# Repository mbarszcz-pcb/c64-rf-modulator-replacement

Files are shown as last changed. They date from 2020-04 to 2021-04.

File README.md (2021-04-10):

# c64-rf-modulator-replacement
C64 Composite/S-Video RF Modulator Replacement

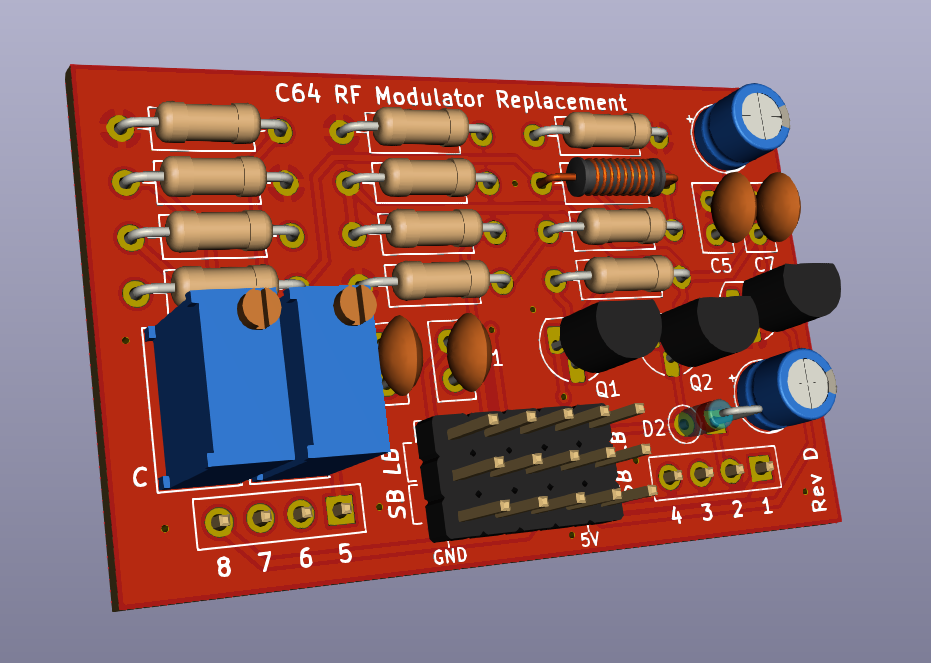
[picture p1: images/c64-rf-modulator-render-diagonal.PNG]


## Quick Links
* [Schematic](pdf/c64-rf-modulator-replacement-schematic.pdf)

* [Gerber Files](gerbers)

* [PCB Renderings](images/pcb)

* [Photos](images/photos)

# Introduction 
This is my version of a C64 RF Modulator replacement based on the schematics of similar designs like [Zero-X/OMS's Modified Commodore RF Modulator Design](images/zerox-oms-modulator_simple-schematic.png) and [JMP$FCE2's S-Video only design](images/jmp$fce2-schematic.png).  This board can be used to replace a damaged or defective RF modulator in your C64, to improve the sharpness of your video output, or as a modern solution to replace the composite/luma/chroma output functionality of the original modulator on new motherboards such as the SixtyClone or Bwack’s KU-14194.

This design has a few goals that set it apart from the others:

1.	It is a universal solution that fits and is electrically compatible with both the C64 and C64C without having to change components on the board or run jumper wires for power.

2.	It is easy and inexpensive to build with only a single, small PCB and all through-hole components.

3.	It provides [high quality S-Video (Y/C) output](images/photos/video-output-6569-r5.png) while maintaining composite video output for compatibility.

4.  It provides adjustable luma/chroma output levels to fine-tune the S-video signal. This allows for the best possible compatibility with a wide variety of different board revisions, VIC chips, aging components and monitors. Adjustable levels  mean this board can also be used with s-video cables with or without an inline resistor to eliminate “checkerboarding” caused by too high of a chroma level.

# Compatibility
This RF modulator replacement is compatible with motherboard revisions 250407, 250425, 250466, and 250469, and both NTSC and PAL VIC-II chips. I have not tested it, but I believe it should also be compatible with Bwack's KU-14194 board as well since it uses the standard longboard RF modulator. It is not compatible, however, with the early revision 326298-01 boards with the 5 Pin AV Output. This revision uses a different modulator pin layout, and the video signals are not combined in the modulator. They are instead processed with discrete components inside the VIC-II can.

# Gathering the components
Kicad files are available for you to view or modify as you see fit. Gerber files are available that can be uploaded directly to your favorite PCB fab to make your own boards, and a complete Bill of Materials (BOM) can be found [here](c64-rf-modulator-replacement-bom.xlsx) with example parts from Digikey. At the time of writing this, the components cost about $12 US, not including the PCB or shipping.

I strongly recommend building the entire board, if you choose to do so, there are a few components that can be omitted in different situations to decrease the cost at the expense of features and flexibility.

## Trimmers
The trim pots used to adjust the luma and chroma are the most expensive components in this project. I highly recommend using them, but if you choose, you may jumper the solder bridges on the back of the board to bypass the trimmer pads and install 150 Ohm resistors for R4 and R7. This won't give you the precision adjustment of the trimmers, but it will be close enough for most configurations. You can experiment with different fixed value resistors between 100-1K Ohm if you want to change fixed output levels.

## No Composite Video
I have not seen any improvement in S-video quality by omitting the composite video components, but if you really don’t want composite output, L2, R8, R11, and C6 can be omitted from the build.

## No Voltage Regulator
If you are only ever going to use the RF modulator replacement on a C64C 250469 short board, you don’t need the voltage regulator or the input/output capacitors since 5V is provided directly to the modulator on pin 1. This means you can omit C3, C5, C7, C8, and U1 from the build.

# Building the board
Once you have your PCBs and all your components, soldering them together should be pretty straightforward. You can use the schematic or the BOM to place the right value parts in the right place. From a soldering standpoint, it is easiest to assemble the components starting with the lowest profile first and then work your way up. This would be mean soldering the resistors and inductor first, then the ceramic caps, the diode, electrolytic capacitors, transistors and voltage regulator, and finally, the jumper block. The jumpers can then be installed on the headers in the appropriate configuration. Finish off by removing the flux residue with some cotton swabs or a brush and isopropyl alcohol.

# Installing the board
First, you need to remove the old RF modulator. This can be a bit tricky as the large metal can will suck the heat right out of the iron. I can’t help you much here, but I can only suggest you use a soldering iron with plenty of heat, use a wide tip, to take your time, and don't rip off any traces. The new board can then be installed one of two ways.

The first is soldering it directly to the motherboard. For this, you can solder two .1” pin headers into the motherboard (making sure they are straight) and then setting the RF modulator replacement down on top of them. I recommend sticking small rubber feet near the rear of the board to help support it. You can slide two feet under the front of the rf modulator replacement to keep the pcb level and evenly spaced all the way around while you solder the headers from the top side. Trim the excess length of the header pins off and slide out the rubber feet. For a nicer finish, reflow the solder joints after you have trimmed them.

Alternatively, you can make the replacement a bit more modular by soldering two 4-pin female headers on the motherboard and two 4-pin male headers on the RF modulator replacement. This will allow you to plug and unplug the modulator easily. It is not required, but as the board will be approximately ½” above the motherboard and “hanging” on the headers, you may want to use some rubber feet, foam, or double-sided tape as a spacer to support the back of the board.

# Adjustments

## Configuring the mainboard
If you are using the longboard (Rev 250407, 250425, 240441, 250466) it is important to make sure the G.PAL/I.PAL jumper by the modulator is SHORTED, or the ground pin the modulator replacement attaches to will be floating and will not work correctly.  You can validate this by checking continity between the left most RF modulator through-hole on the C64 motherboard and a suitable ground point on the C64 motherboard (Cartridge shield, plated edge of the moatherboard, 5V Regulator heatsink, etc).  If the modulator is installed, you can also check continutiy between the bottom left pin on the jumper block and a suitable ground point.

## Jumper Settings
The adjustment of the jumpers routes the signals to the proper pinout for the motherboard you are using, switches the correct pull-up resistor for the VIC-II luma, and enables or disables the use of an onboard 5V regulator.With all jumpers in the up position, the board is configured for use on the 12V C64 “longboards” (250407, 250425, and 250466). In this configuration, the 5V regulator is used to regulate the 9V Unregulated power on pin 1 down to 5V

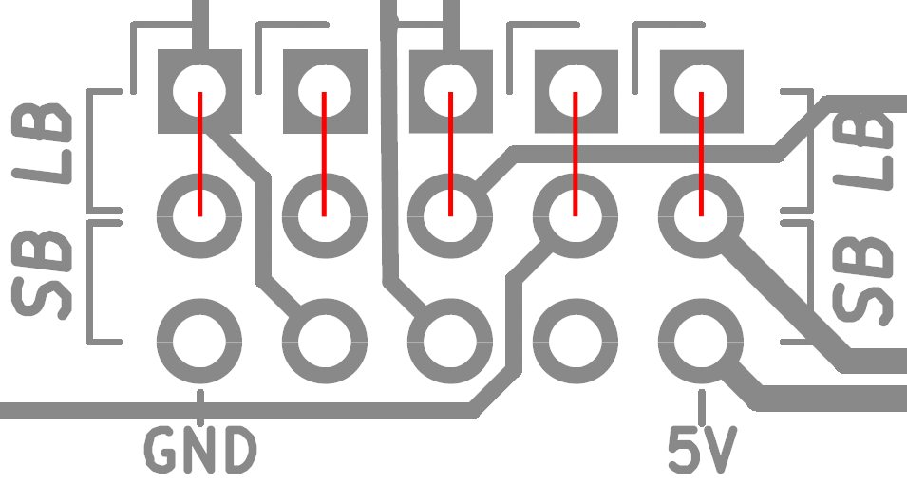
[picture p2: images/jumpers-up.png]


With all jumpers in the down position, the board is configured for use on the 250469 “short board” commonly found in the C64C. In this configuration, the 5V input on pin 1 is fed directly in the circuit without the need for the 5V regulator. Be sure you are using a short board if all the jumpers are down, or you could accidentally fry your VIC-II by accidentally feeding it 9V unreg from a long board.

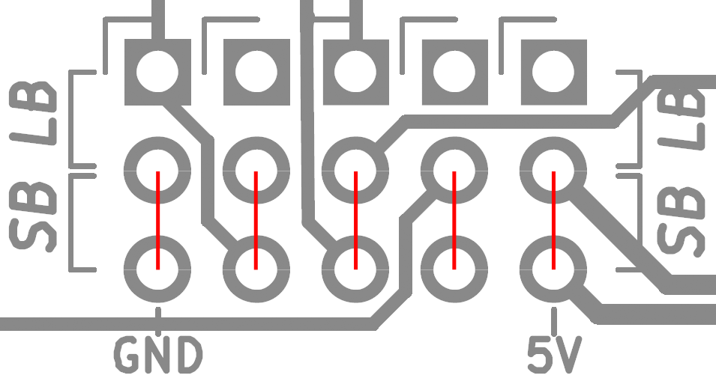
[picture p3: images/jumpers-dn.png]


For most configurations, the jumpers should be either all up or all down; however if you understand what you are doing and want to run a 5V 856x VIC-II from a short board in a 12V long board, there is one jumper that you may want to run in a non-standard configuration. First, you MUST isolate pin 13 on the VIC-II socket from the VIC-II (the short board outputs 12V there while an 856x is expecting 5V). Pin 13 on the VIC-II can then be connected to pin 40 (which is 5V Vcc). I recommend not modifying the VIC-II chips but instead using a piggyback socket or PCB. With a standard machined pin socket, simply trim off leg 13 and solder a jumper wire from leg 13 to 40. The 856x VIC-II can then just plug into the socket without any damaging modifications. Once the VIC-II is installed, the jumpers on the RF modulator should be in the following configuration to use the correct short board 1K pullup resistor:

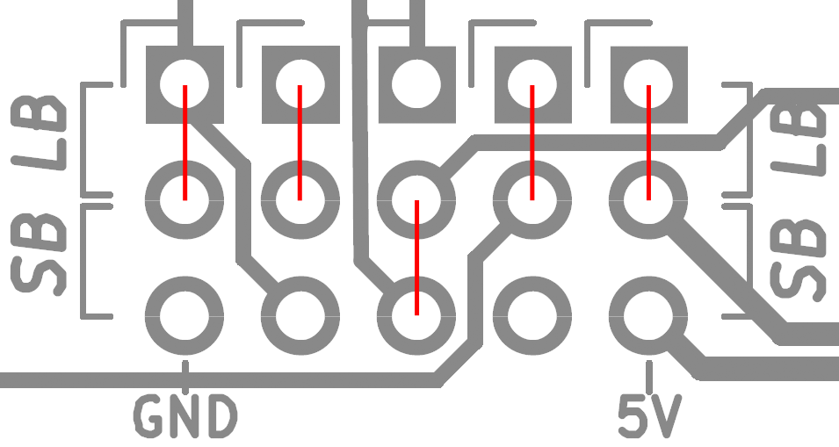
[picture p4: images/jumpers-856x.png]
 	

## Adjusting the Output Level
If you choose to include adjustable potentiometers in your build, a counter-clockwise adjustment on the luma (Y) and chroma (C) potentiometers will reduce the output level. A clockwise adjustment will increase the output level. My recommendation is to start with both adjustments fully counter-clockwise and increase as necessary. The levels can be set with a scope or simply “by eye” depending on the tools you have available.

An ideal chroma signal should be ~300mV peak-to-peak. The adjustment on the board should allow you to adjust it from approximately ~250mV - 1.7V. This range allows you to dial back the output for use with a standard S-video cable or to turn it up to compensate for the cables with the inline 330-1K resistor. Some monitors don't care if the signal is too hot, others will give you an ugly checkered pattern (especially LCDs). If you don't have an oscilloscope to measure the peak-to-peak voltage, start with the chroma pot fully counter-clockwise and increase it until the colors are sufficiently saturated. If you go too far, the image will begin to look “grainy” or have a checkerboard pattern.

Officially, an ideal luma signal should be 1V PP (including the sync pulse). Depending on the output of the VIC-II chip you are using, the adjustment on the board should allow you to adjust it from approximately ~575mV-1.5V PP. The original breadbins output a signal around 1.2V PP, while the later C64Cs were closer to an “in-spec” 1V PP. On some monitors though 1V PP can look too look dark (requiring you to turn up the contrast on your monitor). If using a scope, I would adjust it to approximately 1.1V PP.  If adjusting by eye, start  low and increase the level until the light blue text is reasonably legible against the dark blue background. If the border and text start to look “white” you have gone too far. Another good test on a CRT is white text on a black background. If the white text is blooming, you should back the signal off. The effect will be very similar to having the contrast set too high.

Composite video output remains at a fixed output level regardless of the Y and C adjustment pots.

# A note on use with LCD Monitors and Checkerboarding
If you are still getting checkerboarding even after adjusting the potentiometers, try soldering a 330pF Resistor (you can experiement with different values to see what works best with your setup) across R3 (the resistor on the top right corner of the board).  This combines with R3 to create an RC filter that seems to help eliminate this.  There seems to be a degree of variablility regarding different A->D conversion cirtuitry used in different brands of LCD monitors and in devices like the RetroTink2X or OSSC that makes some displays more susceptable to checkerboarding.  From what I've been able to see, CRT monitors are not susceptable to this behavior.

# Changelog
Rev A – 2020-03-15 - Prototype

Rev B – 2020-03-25 - Initial production revision, fixed schematic bugs, tweaked values and removed unnecessary components to improve picture quality

Rev C – 2020-04-05 - Adjusted positioning of several traces, vias, and regulator U1 to improve physical spacing. Changed RV1 and RV2 for "W" footprint trimmers with inline legs due to parts availability. Swapped R4 and R5 physical locations to better accomodate the new pin configuration

Rev D – 2020-04-07 - Adjusted power and ground trace thickness, added additional vias, added custom trimmer footprint to ID proper placement, optimized ground pours, increased chroma/luma/power trace isolation

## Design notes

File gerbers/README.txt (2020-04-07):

Always use the latest revision PCB.

"-gerbers-jlc.zip" is the PCB with JLCJLCJLC on the B Silkscreen layer for unique ID during board production and proper options for JLCPCB.  Be sure to select "specify a location" when ordering from JLCPCB.

"-gerbers-pcbway.zip" are the gerbers exported with the proper options for pcbway

Recommended board values:
	PCB Thickness: 1.6mm
	Copper Weight 1oz
	Castellated Holes - No
	Tented Vias - Yes
	Surface Finish - Personal preference

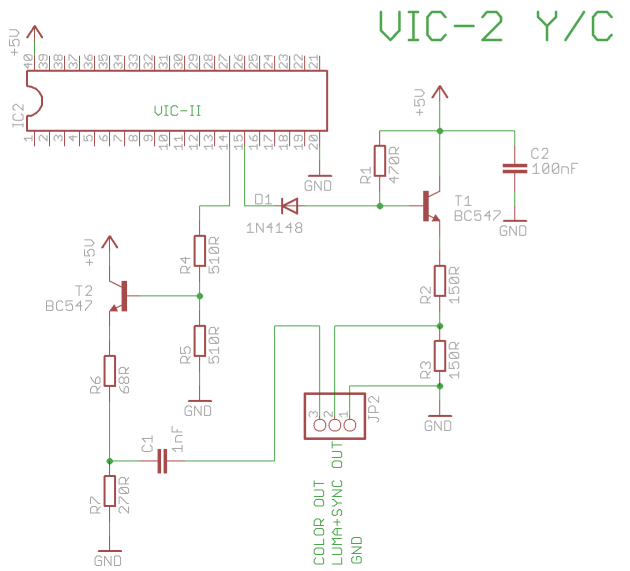
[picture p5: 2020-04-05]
images/jmp$fce2-schematic.png

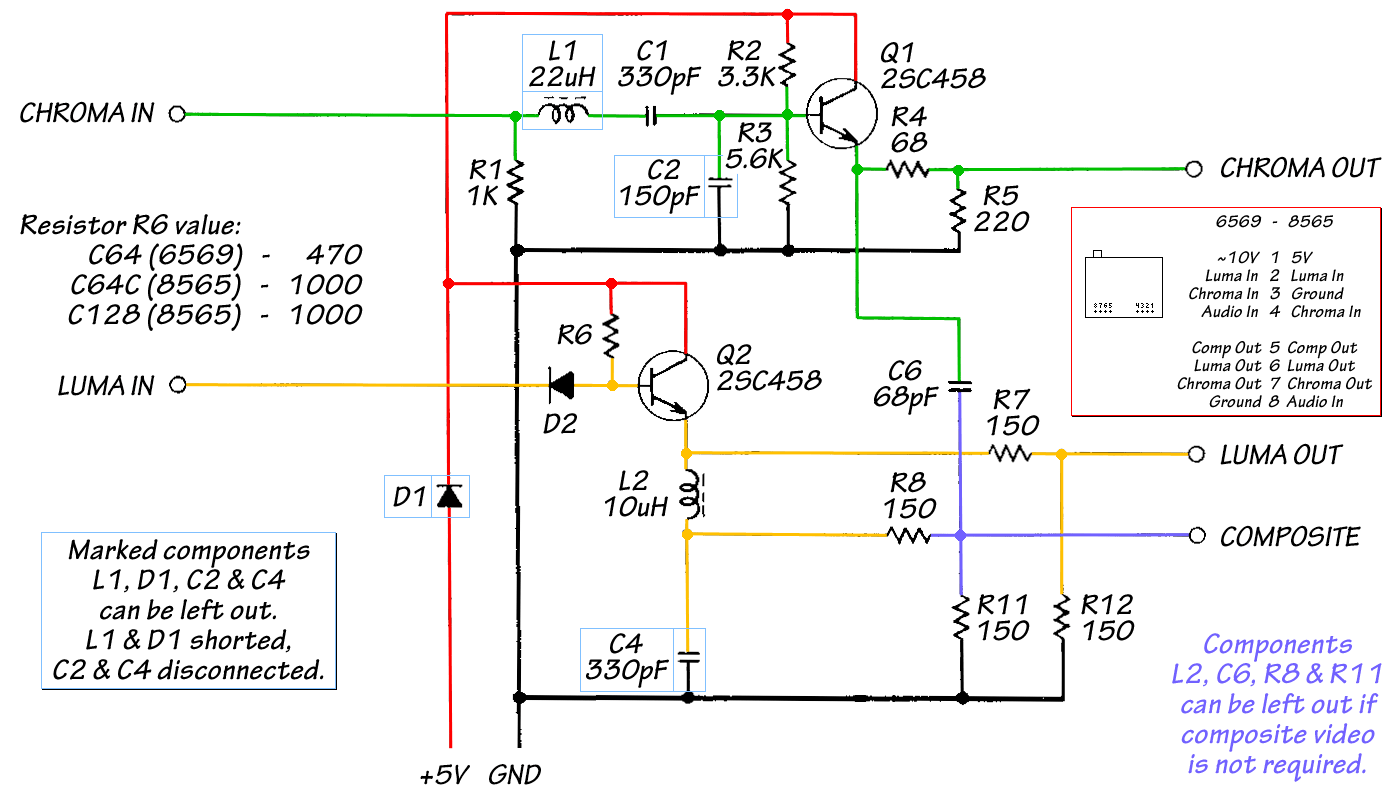
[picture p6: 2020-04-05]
images/zerox-oms-modulator_simple-schematic.png

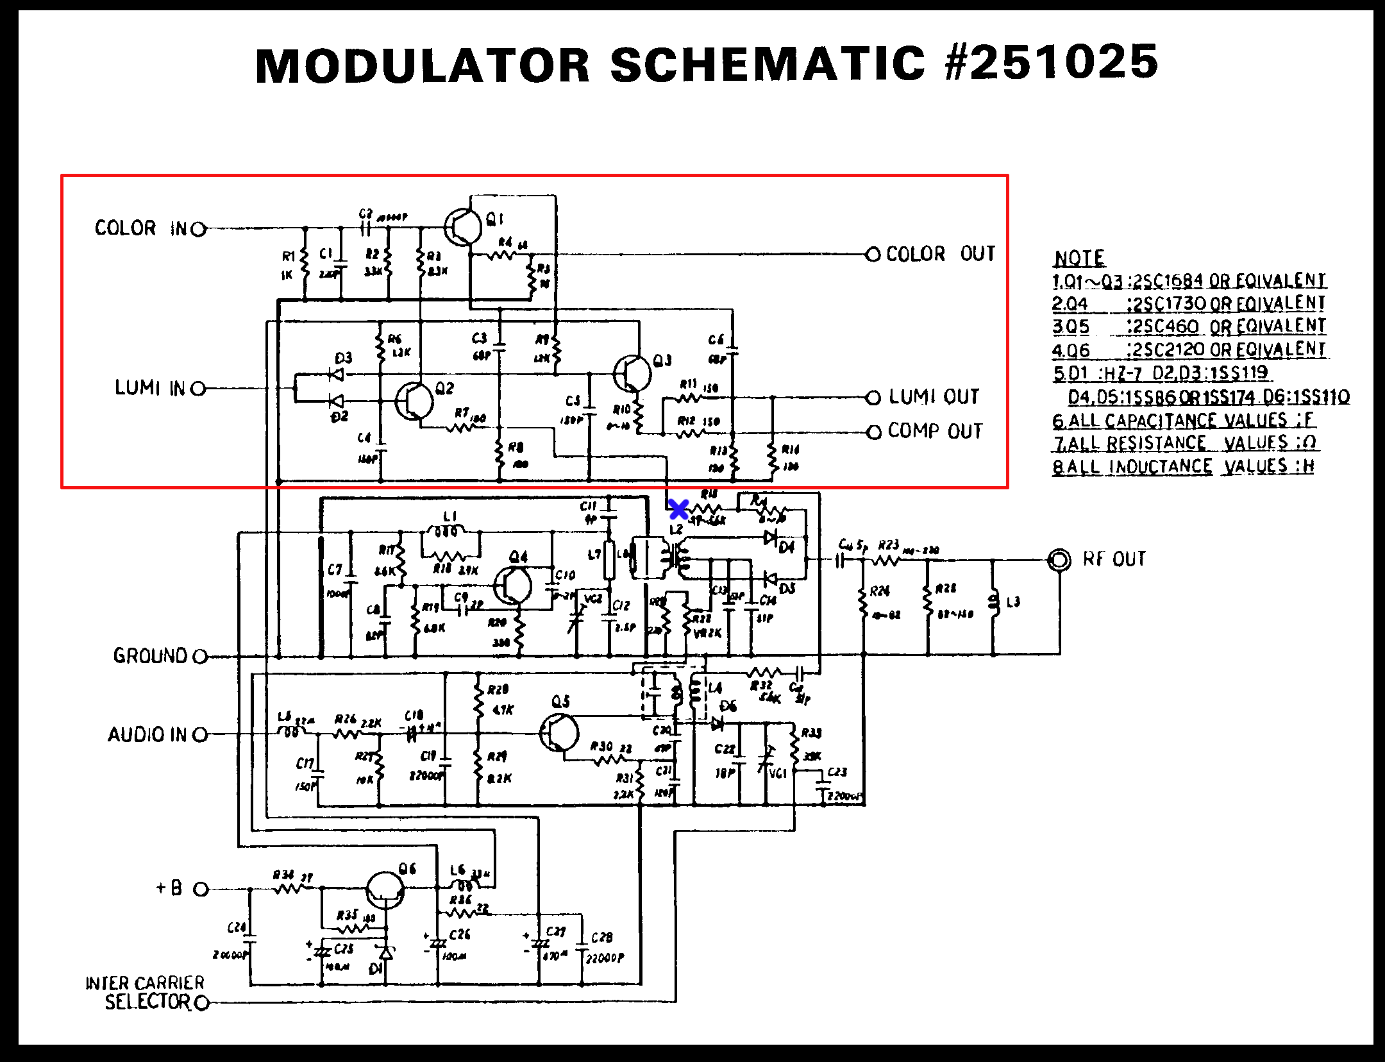
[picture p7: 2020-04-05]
images/modulator-251025-schematic.png

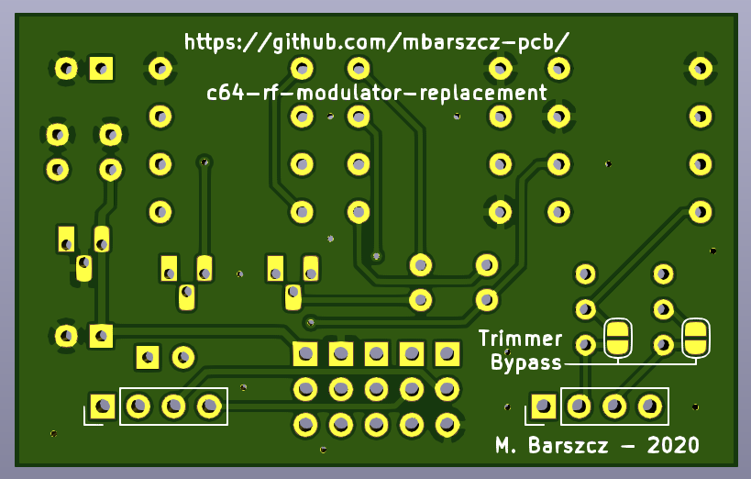
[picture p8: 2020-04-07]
images/pcb/c64-rf-modulator-pcb-bottom.PNG

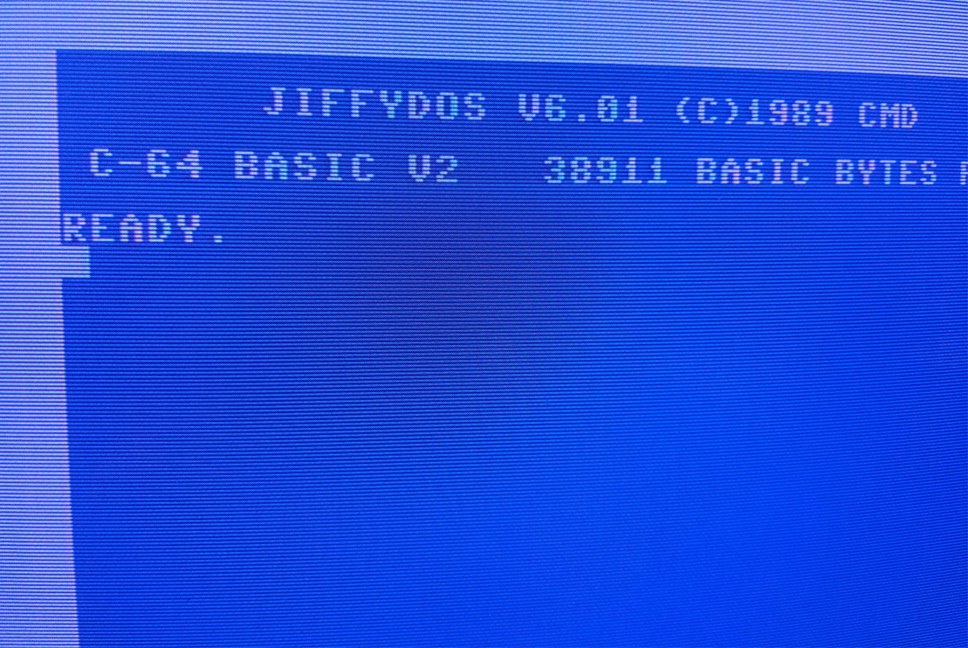
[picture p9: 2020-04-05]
images/photos/video-output-6569-r5.png

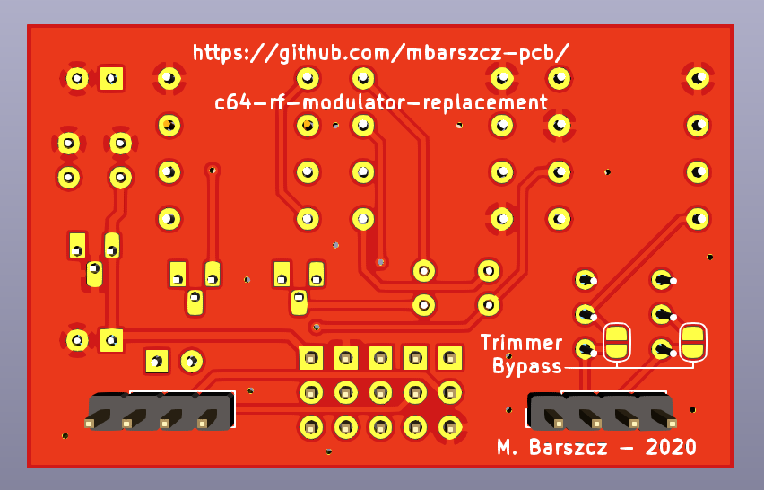
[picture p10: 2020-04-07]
images/c64-rf-modulator-render-bottom.PNG

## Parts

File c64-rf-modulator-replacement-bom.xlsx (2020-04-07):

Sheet: RevB
Quantity | Customer Reference | Description | Digi-Key Part Number | Digi-Key Description | Manufacturer | Manufacturer Part Number | Notes
1 | C1 | 330pF Ceramic Capacitor - "331" | 478-11694-ND | CAP CER 330PF 100V C0G/NP0 RAD | AVX Corporation | SR151A331JAA
1 | C5 | 0.33uF Ceramic Capacitor - "334" | 478-5733-ND | CAP CER 0.33UF 50V Z5U RADIAL | AVX Corporation | SR205E334MAR
1 | C6 | 68pF Ceramic Capacitor - "680" | 478-5215-ND | CAP CER 68PF 100V NP0 RADIAL | AVX Corporation | SR151A680JAR
1 | C7 | 0.1uF Ceramic Capacitor - "104" | 478-3192-ND | CAP CER 0.1UF 50V Z5U RADIAL | AVX Corporation | SR205E104MAR
2 | C3,C8 | 10uF Electrolytic Capacitor | 493-17440-1-ND | CAP ALUM 10UF 20% 25V RADIAL | Nichicon | USV1E100MFD1TP
1 | L2 | 10uH Inductor | M10135-ND | FIXED IND 10UH 370MA 750 MOHM TH | Bourns Inc. | 78F100J-RC
1 | D2 | 1N4148 Diode | 1N4148FS-ND | DIODE GEN PURP 100V 200MA DO35 | ON Semiconductor | 1N4148
2 | R1,R62 | 1K Ohm 1/4W Resistor | CF14JT1K00CT-ND | RES 1K OHM 1/4W 5% AXIAL | Stackpole Electronics Inc | CF14JT1K00
1 | R2 | 3.3K Ohm 1/4W Resistor | CF14JT3K30CT-ND | RES 3.3K OHM 1/4W 5% AXIAL | Stackpole Electronics Inc | CF14JT3K30
1 | R3 | 5.6K Ohm 1/4W Resistor | CF14JT5K60CT-ND | RES 5.6K OHM 1/4W 5% AXIAL | Stackpole Electronics Inc | CF14JT5K60
1 | R4 | 68 Ohm 1/4W Resistor | CF14JT68R0CT-ND | RES 68 OHM 1/4W 5% AXIAL | Stackpole Electronics Inc | CF14JT68R0
1 | R5 | 220 Ohm 1/4W Resistor | CF14JT220RCT-ND | RES 220 OHM 1/4W 5% AXIAL | Stackpole Electronics Inc | CF14JT220R
1 | R7 | 75 Ohm 1/4W Resistor | CF14JT75R0CT-ND | RES 75 OHM 1/4W 5% AXIAL | Stackpole Electronics Inc | CF14JT75R0 | Use with RV2=220 Ohm (Preferred)
3 | R8,R11,R12 | 150 Ohm 3/4W Resistor | CF14JT150RCT-ND | RES 150 OHM 1/4W 5% AXIAL | Stackpole Electronics Inc | CF14JT150R
1 | R61 | 470 Ohm 1/4W Resistor | CF14JT470RCT-ND | RES 470 OHM 1/4W 5% AXIAL | Stackpole Electronics Inc | CF14JT470R
1 | RV1 | 1K Ohm 25 Turn Trimpot - Chroma Adjustment (Triangular pin configuration - "Y") | 3296Y-102LF-ND | TRIMMER 1K OHM 0.5W PC PIN TOP | Bourns Inc. | 3296Y-1-102LF | If omitted, use R4=150 Ohm
1 | RV2 | 220 Ohm 25 Turn Trimpot - Luma Adjustment (In-line pin configuration - "W") | 3296W-1-221LF-ND | TRIMMER 220 OHM 0.5W PC PIN TOP | Bourns Inc. | 3296W-1-221LF | If omitted, use R7=150 Ohm Note, you will have to bend the legs to make it work fit as the 220 doesn't come in a "Y" leg configuration, only the straight legs "W"
2 | Q1,Q2 | BC547B NPN Transistor | BC547BFS-ND | TRANS NPN 45V 0.1A TO-92 | ON Semiconductor | BC547B
1 | U1 | 5V 78L05 Linear Regulator | 497-7268-ND | IC REG LINEAR 5V 100MA TO92-3 | STMicroelectronics | L78L05CZ
1 | 3x5 Jumper Block | 3x5 Pin Header | SAM12316-ND | CONN HEADER VERT 15POS 2.54MM | Samtec Inc. | TSW-105-07-F-T
5 | Jumpers | 0.1" Jumpers | S9337-ND | CONN JUMPER SHORTING .100" GOLD | Sullins Connector Solutions | QPC02SXGN-RC

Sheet: RevC-D
Quantity | Customer Reference | Description | Digi-Key Part Number | Digi-Key Description | Manufacturer | Manufacturer Part Number | Notes
1 | C1 | 330pF Ceramic Capacitor - "331" | 478-11694-ND | CAP CER 330PF 100V C0G/NP0 RAD | AVX Corporation | SR151A331JAA
1 | C5 | 0.33uF Ceramic Capacitor - "334" | 478-5733-ND | CAP CER 0.33UF 50V Z5U RADIAL | AVX Corporation | SR205E334MAR
1 | C6 | 68pF Ceramic Capacitor - "680" | 478-5215-ND | CAP CER 68PF 100V NP0 RADIAL | AVX Corporation | SR151A680JAR
1 | C7 | 0.1uF Ceramic Capacitor - "104" | 478-3192-ND | CAP CER 0.1UF 50V Z5U RADIAL | AVX Corporation | SR205E104MAR
2 | C3,C8 | 10uF Electrolytic Capacitor | 493-17440-1-ND | CAP ALUM 10UF 20% 25V RADIAL | Nichicon | USV1E100MFD1TP
1 | L2 | 10uH Inductor | M10135-ND | FIXED IND 10UH 370MA 750 MOHM TH | Bourns Inc. | 78F100J-RC
1 | D2 | 1N4148 Diode | 1N4148FS-ND | DIODE GEN PURP 100V 200MA DO35 | ON Semiconductor | 1N4148
2 | R1,R62 | 1K Ohm 1/4W Resistor | CF14JT1K00CT-ND | RES 1K OHM 1/4W 5% AXIAL | Stackpole Electronics Inc | CF14JT1K00
1 | R2 | 3.3K Ohm 1/4W Resistor | CF14JT3K30CT-ND | RES 3.3K OHM 1/4W 5% AXIAL | Stackpole Electronics Inc | CF14JT3K30
1 | R3 | 5.6K Ohm 1/4W Resistor | CF14JT5K60CT-ND | RES 5.6K OHM 1/4W 5% AXIAL | Stackpole Electronics Inc | CF14JT5K60
1 | R4 | 68 Ohm 1/4W Resistor | CF14JT68R0CT-ND | RES 68 OHM 1/4W 5% AXIAL | Stackpole Electronics Inc | CF14JT68R0
1 | R5 | 220 Ohm 1/4W Resistor | CF14JT220RCT-ND | RES 220 OHM 1/4W 5% AXIAL | Stackpole Electronics Inc | CF14JT220R
1 | R7 | 75 Ohm 1/4W Resistor | CF14JT75R0CT-ND | RES 75 OHM 1/4W 5% AXIAL | Stackpole Electronics Inc | CF14JT75R0
3 | R8,R11,R12 | 150 Ohm 3/4W Resistor | CF14JT150RCT-ND | RES 150 OHM 1/4W 5% AXIAL | Stackpole Electronics Inc | CF14JT150R
1 | R61 | 470 Ohm 1/4W Resistor | CF14JT470RCT-ND | RES 470 OHM 1/4W 5% AXIAL | Stackpole Electronics Inc | CF14JT470R
1 | RV1 | 1K Ohm 25 Turn Trimpot - Chroma Adjustment (In-line pin configuration - "W") | 3296W-102LF-ND | TRIMMER 1K OHM 0.5W PC PIN TOP | Bourns Inc. | 3296W-1-102LF | If omitted, use R4=150 Ohm
1 | RV2 | 220 Ohm 25 Turn Trimpot - Luma Adjustment (In-line pin configuration - "W") | 3296W-1-221LF-ND | TRIMMER 220 OHM 0.5W PC PIN TOP | Bourns Inc. | 3296W-1-221LF | If omitted, use R7=150 Ohm
2 | Q1,Q2 | BC547B NPN Transistor | BC547BFS-ND | TRANS NPN 45V 0.1A TO-92 | ON Semiconductor | BC547B
1 | U1 | 5V 78L05 Linear Regulator | 497-7268-ND | IC REG LINEAR 5V 100MA TO92-3 | STMicroelectronics | L78L05CZ
1 | 3x5 Jumper Block | 3x5 Pin Header | SAM12316-ND | CONN HEADER VERT 15POS 2.54MM | Samtec Inc. | TSW-105-07-F-T
5 | Jumpers | 0.1" Jumpers | S9337-ND | CONN JUMPER SHORTING .100" GOLD | Sullins Connector Solutions | QPC02SXGN-RC

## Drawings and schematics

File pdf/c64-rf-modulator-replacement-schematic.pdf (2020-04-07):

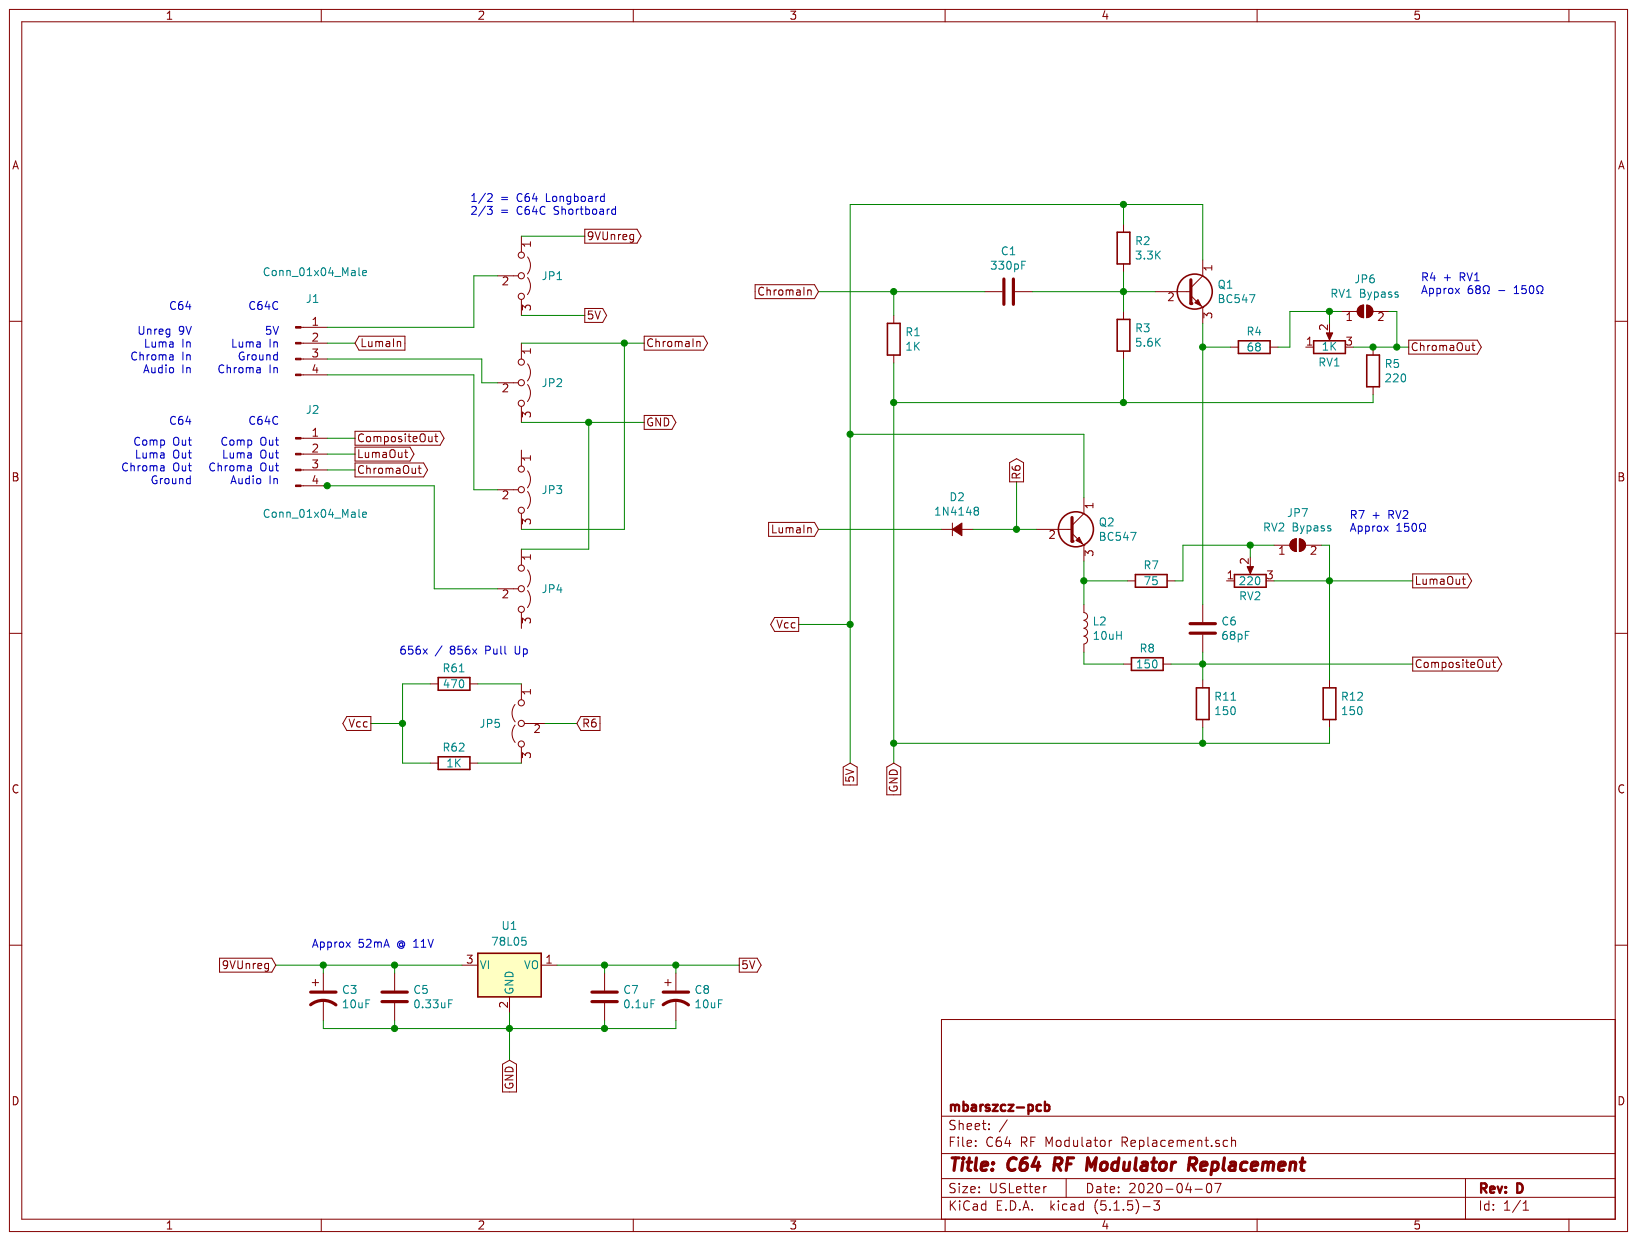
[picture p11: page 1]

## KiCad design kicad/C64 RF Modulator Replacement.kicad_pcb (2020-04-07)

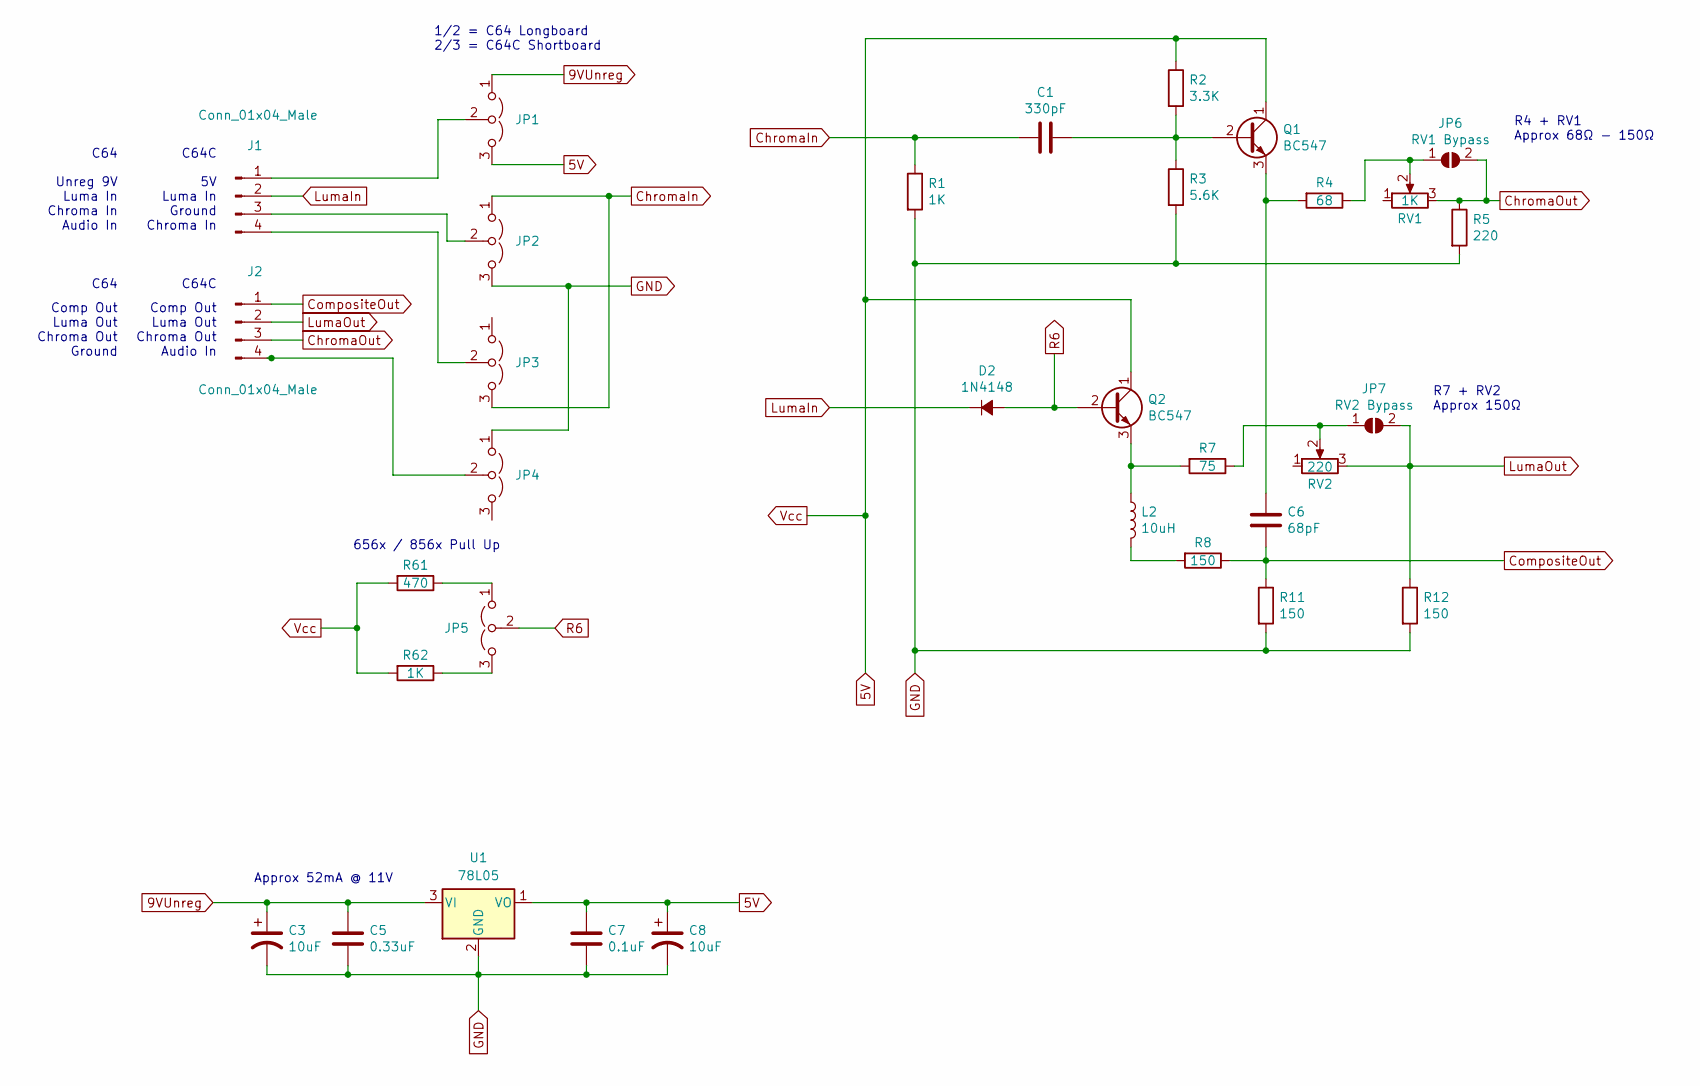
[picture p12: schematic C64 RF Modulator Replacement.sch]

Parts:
C1: 330pF; C_Disc_D5.0mm_W2.5mm_P2.50mm
C3, C8: 10uF; CP_Radial_D5.0mm_P2.50mm
C5: 0.33uF; C_Disc_D5.0mm_W2.5mm_P2.50mm
C6: 68pF; C_Disc_D5.0mm_W2.5mm_P2.50mm
C7: 0.1uF; C_Disc_D5.0mm_W2.5mm_P2.50mm
D2: 1N4148; D_DO-35_SOD27_P2.54mm_Vertical_KathodeUp
J1, J2: Conn_01x04_Male; PinHeader_1x04_P2.54mm_Vertical
JP1, JP2, JP3, JP4, JP5: Jumper_3_Open; PinHeader_1x03_P2.54mm_Vertical-NoSilk
JP6: RV1 Bypass; SolderJumper-2_P1.3mm_Open_RoundedPad1.0x1.5mm
JP7: RV2 Bypass; SolderJumper-2_P1.3mm_Open_RoundedPad1.0x1.5mm
L2: 10uH; L_Axial_L6.6mm_D2.7mm_P10.16mm_Horizontal_Vishay_IM-2
Q1, Q2: BC547; TO-92_HandSolder
R1, R62: 1K; R_Axial_DIN0207_L6.3mm_D2.5mm_P10.16mm_Horizontal
R2: 3.3K; R_Axial_DIN0207_L6.3mm_D2.5mm_P10.16mm_Horizontal
R3: 5.6K; R_Axial_DIN0207_L6.3mm_D2.5mm_P10.16mm_Horizontal
R4: 68; R_Axial_DIN0207_L6.3mm_D2.5mm_P10.16mm_Horizontal
R5: 220; R_Axial_DIN0207_L6.3mm_D2.5mm_P10.16mm_Horizontal
R7: 75; R_Axial_DIN0207_L6.3mm_D2.5mm_P10.16mm_Horizontal
R8, R11, R12: 150; R_Axial_DIN0207_L6.3mm_D2.5mm_P10.16mm_Horizontal
R61: 470; R_Axial_DIN0207_L6.3mm_D2.5mm_P10.16mm_Horizontal
RV1: 1K; Potentiometer_Bourns_3296W_Vertical
RV2: 220; Potentiometer_Bourns_3296W_Vertical
U1: 78L05; TO-92_HandSolder

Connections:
5V: C7.1, C8.1, JP1.3 (B), Q1.1 (C), Q2.1 (C), R2.1, R61.2, R62.2, U1.1 (VO)
9VUnreg: C3.1, C5.1, JP1.1 (A), U1.3 (VI)
ChromaIn: C1.1, JP2.1 (A), JP3.3 (B), R1.1
ChromaOut: J2.3, JP6.2 (B), R5.1, RV1.3
CompositeOut: C6.2, J2.1, R8.1, R11.1
GND: C3.2, C5.2, C7.2, C8.2, JP2.3 (B), JP4.1 (A), R1.2, R3.2, R5.2, R11.2, R12.2, U1.2 (GND)
LumaIn: D2.1 (K), J1.2
LumaOut: J2.2, JP7.2 (B), R12.1, RV2.3
unnamed: C1.2, Q1.2 (B), R2.2, R3.1
unnamed: C6.1, Q1.3 (E), R4.2
unnamed: J1.1, JP1.2 (C)
unnamed: J1.3, JP2.2 (C)
unnamed: J1.4, JP3.2 (C)
unnamed: J2.4, JP4.2 (C)
unnamed: JP5.1 (A), R61.1
unnamed: JP5.3 (B), R62.1
unnamed: JP6.1 (A), R4.1, RV1.2
unnamed: JP7.1 (A), R7.1, RV2.2
unnamed: L2.1, Q2.3 (E), R7.2
unnamed: L2.2, R8.2
R6: D2.2 (A), JP5.2 (C), Q2.2 (B)

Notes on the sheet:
Unreg 9V Luma In Chroma In Audio In
Comp Out Luma Out Chroma Out Ground
5V Luma In Ground Chroma In
Comp Out Luma Out Chroma Out Audio In
C64
C64C
1/2 = C64 Longboard 2/3 = C64C Shortboard
656x / 856x Pull Up
Approx 52mA @ 11V
R4 + RV1 Approx 68Ω - 150Ω
R7 + RV2 Approx 150Ω

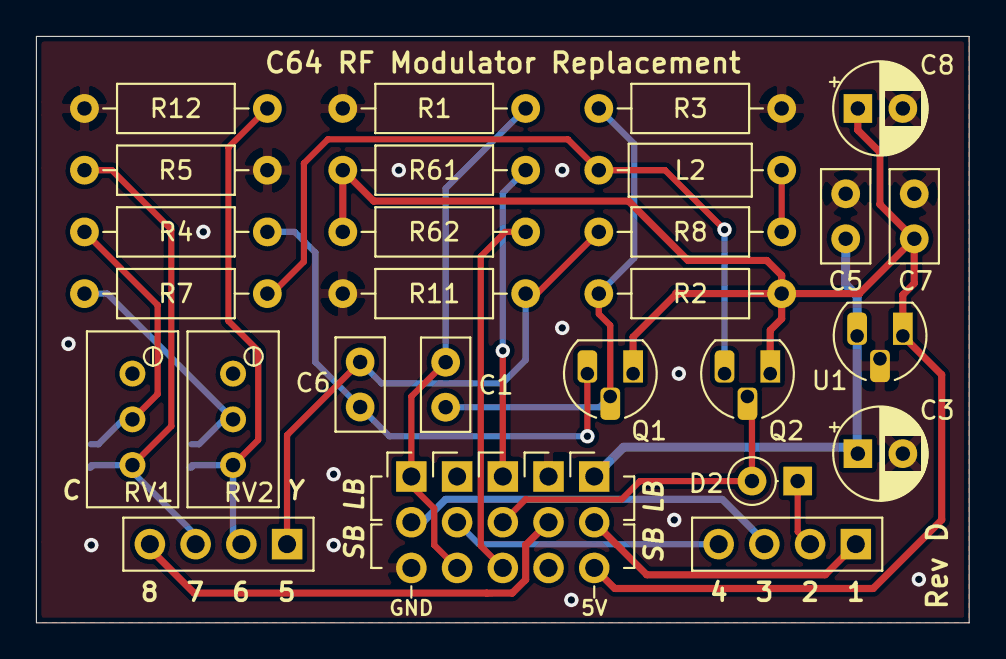
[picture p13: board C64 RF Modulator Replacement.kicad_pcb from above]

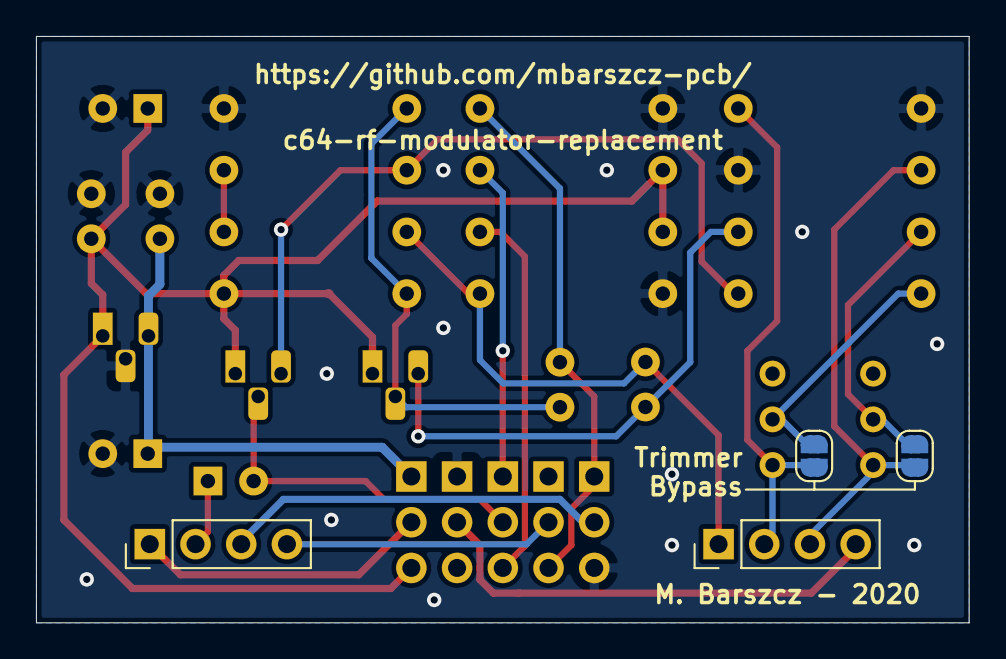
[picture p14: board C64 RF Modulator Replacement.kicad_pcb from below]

Board: 2 copper layers, 51.8 x 32.6 mm, 33 parts (4 on the bottom side), 21 nets.

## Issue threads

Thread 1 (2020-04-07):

revD Gerber files

xiphias256, 2020-04-07:
Hi!

Tried to upload your rev.D gerber files to PCBWay, and I got feedback that the files was not in the right format. Rev. C uploads and reviews fine.

Error message: "We need gerber file in fomat of RS-274x;"

mbarszcz-pcb, 2020-04-07:
I think I know the problem.  Let me export some new ones and upload them..
They'll be listed as -pcbway.

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

xiphias256, 2020-04-07:
Thanks!
PCBWay accepted the new file.

Closed 2020-04-07.

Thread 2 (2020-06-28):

Swapped resistors in photo

MagerValp, 2020-06-28:
It looks like R4 and R5 have been swapped in the photo here:

https://github.com/mbarszcz-pcb/c64-rf-modulator-replacement/blob/master/images/photos/c64-rf-modulator-photo-inst.png

I was using the photo as a reference when assembling and it had me confused for a bit :)

mbarszcz-pcb, 2020-06-28:
The example photo is from the earlier Rev B of the board.  The latest Rev D has the physical positions swapped, but the values still match their reference IDs.  When assembling the PCB please be sure to match the component values and reference IDs on the schematic with the reference IDs on the board's silkscreen.

Closed 2020-06-28.

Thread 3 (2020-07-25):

GND on long boards.

bwack, 2020-07-25:
Hi, I'm helping a guy on facebook regarding ground on long boards. He noticed that the GND is not mentioned in the readme (under jumper settings). I'm just presuming from the schematics, that the G.PAL jumper on the mother board must be joined/solder-blobbed for it to work ?
Looks neat btw !! :)

modeler, 2020-07-25:
I am that guy, and thank you bwack for helping out. With the original modulator in place, the far-left of the eight pins (as you look at the top of the board) is connected to ground via the modulator housing. When removed, the pin is not connected to ground unless the G.PAL jumper is shorted as bwack says.

Thank you for this project!

mbarszcz-pcb, 2020-07-25:
I didn't see the issue on Facebook and never noticed before that pin "8" (gnd on the long boards) is only gnd when the G.PAL jumper is closed.

Looking at the notes in the original commodore schematic, it seems that the jumper's original function would have been to change the sound carrier in the original modulator.  Since no audio is passing through the RF modulator replacement anymore (or being modulated onto an RF signal), I guess the easiest thing would just be to make sure that jumper is closed when using the RF Modulator.  Was that the solution you came to as well?

bwack, 2020-07-26:
Yes!

Closed 2020-09-30.

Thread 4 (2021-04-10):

UK PAL 250407 boards have floating ground pin to the modulator

davepoo, 2021-04-10:
Not really an issue but making you aware that UK PAL 250407 boards have floating ground pin to the modulator. So your modulator replacement actually requires the solder jumper on the board to be connected to make the ground good, or it will be loaded with interference. Might be worth adding a note about this to the readme.

https://youtu.be/jXSQe5f-Rsk?t=428

I made a video on this while i was installing the modulator replacement (the bad ram and other fails on the computer are not related this ground problem)

davepoo, 2021-04-10:
Oh and accoring to the internet. https://www.cavsi.com/questionsanswers/what-are-the-pal-variants/
This "I Pal" with the open ground will affect "UK, Ireland, Hong Kong and Macau" versions of the boards.

There are five varieties of PAL:

1. PAL B/G/D/K/I
The majority of countries using PAL have television standards with 625 lines and 25 frames, differences concern the audio carrier frequency and channel bandwidths. Standards B/G are used in most of Western Europe, standard I in the UK, Ireland, Hong Kong and Macau, standards D/K in most of Eastern Europe and Standard D in mainland China.

7-MHz channels are used in VHF (B, D) and 8-MHz channels in UHF (G, K, I), although Australia used 7-MHz channels in UHF and Ireland uses 8-MHz channels in VHF .

davepoo, 2021-04-10:
Actually, i've just noticed that there was already a closed issue for this
https://github.com/mbarszcz-pcb/c64-rf-modulator-replacement/issues/3

Too late, i had to figure it out myself.

mbarszcz-pcb, 2021-04-10:
Thanks for bringing this to my attention (again).  I will add a section to the main page regarding this to hopefully eliminate confusion in the future.  None of my boards had that jumper open so it never came up for me.  The ground pin was just...ground.

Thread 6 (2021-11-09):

Could this work on the C16 as well?

SukkoPera, 2021-11-09:
Hi, thanks for your project. I was wondering if this circuit could work in the Commodore 16, too. I am asking because I would like to integrate it in [a clone mainboard I am making](https://github.com/SukkoPera/LittleSixteen) (with the obvious modifications for power, input signals, etc).

Here are the schematics of the C16/Plus4 modulator, taken from [the Service Manual](https://github.com/SukkoPera/LittleSixteen/blob/master/doc/C16_Service_Manual_314001-03_(1984_Oct).pdf).

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

Your schematics look similar but not exactly the same. Do you think I could have a go with your circuit, which is a bit simpler and more tailorable (I like the pots!) or should I use the exact circuit from the above?

Thanks for your time! :)

SukkoPera, 2021-11-14:
Same schematics as above with RF stuff removed. The similarity with this project is now more evident.

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

SukkoPera, 2021-11-14:
I have modified the schematics of this project adding the missing components and noting the different values of other components:
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

Now, the 3 added caps and the added inductor are also present, with similar values, in the [schematics of the 251696 modulator for the C64](http://www.zimmers.net/anonftp/pub/cbm/schematics/computers/c64/modulator-251696.gif), which makes me think they aren't critical, if they were omitted from this project. This is also stated explicitly in [this other C64 modulator replacement circuit I've found](https://i2.wp.com/oms.wmhost.com/misc/modulator_simple.png?zoom=2).

The rest of the circuit is exactly the same as this project's, with only a few different values. I don't have the knowledge to judge whether the different values are critical or not, but I think I can dare say that **the circuit of this project will probably work on the C16 as well**, possibly with a few different values for some components. I guess I'll go with it for the prototype of my boards. Once they are manufactured I will do some testing and report back.

Note that the current board of this project will NOT be a drop-in replacement for the C16, as the connecting pins are placed differently, some redesign will be needed.

mbarszcz-pcb, 2021-11-22:
I'm sorry I am not familiar with the C16 enough to be able to judge whether it will work or not.

SukkoPera, 2021-12-22:
No problem, we went ahead and ordered the boards. We'll soon find out :).

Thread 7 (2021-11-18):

150 Ohm 3/4W Resistor

inter981, 2021-11-18:
Hi, in the bom list, i see in the decription there's needed 150 Ohm 3/4W Resistors for R8,R11,R12...
Sure they are 3/4W or is a mistake?

Kindly regards!

mbarszcz-pcb, 2021-11-22:
You are correct, that is a typo.  It should be 1/4W like the rest.

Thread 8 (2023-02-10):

Components R4 and R5 misplaced on the example photo?

reijndert, 2023-02-10:
I assume the schematic is ok, but
https://github.com/mbarszcz-pcb/c64-rf-modulator-replacement/blob/master/images/photos/c64-rf-modulator-photo-inst.png
the components on position R4 and R5 switched places?
68 ohms and 220 ohms.
Swapping the components doesnt match with  "r4+rv1 approx 68-150" since it starts with 220?

But of course (r4/rv1) and (r5) are a voltage divider and the chroma-out level is still perfectly manageble.

Cheers!

mbarszcz-pcb, 2023-02-12:
You are correct, they did switch places in Rev C.  The example photo was from Rev B.

Rev C – 2020-04-05 - Adjusted positioning of several traces, vias, and regulator U1 to improve physical spacing. Changed RV1 and RV2 for "W" footprint trimmers with inline legs due to parts availability. **Swapped R4 and R5 physical locations to better accomodate the new pin configuration**

Closed 2023-02-12.

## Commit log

2020-04-05 intial upload
    [C64 RF Modulator Replacement.kicad_pcb, C64 RF Modulator Replacement.sch]
2020-04-05 rearranged folder structure
    [C64 RF Modulator Replacement.kicad_pcb, C64 RF Modulator Replacement.sch]
2020-04-05 Rev C
    [C64 RF Modulator Replacement.kicad_pcb, C64 RF Modulator Replacement.sch, c64-rf-modulator-replacement-bom.xlsx]
2020-04-05 moved gerbers, updated title image
2020-04-07 Rev D
    [C64 RF Modulator Replacement.kicad_pcb, C64 RF Modulator Replacement.sch, c64-rf-modulator-replacement-bom.xlsx]
2020-04-07 uploaded revD pcbway
